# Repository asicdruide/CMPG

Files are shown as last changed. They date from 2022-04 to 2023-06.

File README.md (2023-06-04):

# CMPG
Plate Generator for CindyMill

CNC mills are cool machines. CindyMill is one of those.
see also:
* http://cindymill.xyz/ 
* https://github.com/culturalheritagedigital/Cindymill

This repository provides a set of python scripts to draw the needed parts as dxf.
Advantage is that you can easily do adaptions even if you have no access to a full blown CAD system.

It's based on python and the ezdxf module (btw great stuff).

This is work-in-progress, if you use it, you do it on your own risk.

Planned improvements:
 * ~~central setup file for all parameters~~ (done)
 * more dependencies calculated (lesser magic numbers)
 * ~~output for non-plate values like extrusion length~~ (done)
 * ~~parts library for common parts~~ (done)

### How to run

python cmpg.py 

will re-generate everything under sub-folder 'generated'.

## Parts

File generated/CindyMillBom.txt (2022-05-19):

DIN125       M3   ......................... 54 needed....stock(    ).......to be sourced(    )
    2 (mounting Z-limit switches)
    4 (mounting XY-limit switches)
    8 (Portal-side-left to Y-MGN12H)
    8 (Portal-side-right to Y-MGN12H)
   16 (ZAxis-front to Z-MGN12H)
   16 (ZAxis-back X-MGN12H)
 
DIN125       M4   .........................  6 needed....stock(    ).......to be sourced(    )
    6 (1204 nut to nut holder)
 
DIN125       M5   .........................250 needed....stock(    ).......to be sourced(    )
   18 (1605 nut to nut holder)
   16 (brackets at inner frame corners)
    8 (Frame-front-left to Y-extrusion)
    8 (Frame-front-left to frameX-extrusion)
    8 (Y-BF12 to Frame-front-left)
    8 (Frame-front-right to Y-extrusion)
    8 (Frame-front-right to frameX-extrusion)
    8 (Y-BF12 to Frame-front-right)
    8 (Frame-back-left to Y-extrusion)
    8 (Frame-back-left to frameX-extrusion)
    8 (Y-NEMA23 to Frame-back-left)
    8 (Frame-back-right to Y-extrusion)
    8 (Frame-back-right to frameX-extrusion)
    8 (Y-NEMA23 to Frame-back-right)
    8 (Y-BK12 to Frame-block-left)
    8 (Y-BK12 to Frame-block-right)
    4 (Portal-side-left to Y-1605 nut holder)
   12 (Portal-side-left to portalX-extrusion)
    8 (X-BF12 to Portal-side-left)
    4 (Portal-side-right to Y-1605 nut holder)
   12 (Portal-side-right to portalX-extrusion)
    8 (X-NEMA23 to Portal-side-right)
   20 (Portal-back to portal)
    8 (X-BK12 to Portal-block)
    4 (ZAxis-front to Z-1204 nutholder)
    2 (ZAxis-bottom to Z-extrusion)
    8 (Z-NEMA23 to ZAxis-top)
    2 (ZAxis-top to Z-extrusion)
    4 (ZAxis-back to X-1605 nutholder)
    8 (Z-extrusion to ZAxis-back)
 
DIN125       M6   ......................... 36 needed....stock(    ).......to be sourced(    )
    4 (block to Frame-back-left)
    4 (block to Frame-back-right)
    4 (Frame-block-left to Frame-back)
    4 (Frame-block-right to Frame-back)
    4 (steel socket to Portal-side-right)
    4 (Portal-block to steel socket)
    6 (spindle_adapter to ZAxis-front)
    2 (Z-BF10 to ZAxis-back)
    4 (Z-BK10 to ZAxis-back)
 
DIN912       M3x10......................... 20 needed....stock(    ).......to be sourced(    )
    4 (mounting XY-limit switches)
   16 (ZAxis-front to Z-MGN12H)
 
DIN912       M3x16......................... 34 needed....stock(    ).......to be sourced(    )
    2 (mounting Z-limit switches)
    8 (Portal-side-left to Y-MGN12H (exact:15))
    8 (Portal-side-right to Y-MGN12H (exact:15))
   16 (ZAxis-back X-MGN12H (exact:15))
 
DIN912       M3x8 .........................144 needed....stock(    ).......to be sourced(    )
   58 (Xrails to extrusion)
   64 (Yrails to extrusion)
   22 (Zrails to extrusion)
 
DIN912       M4x18.........................  6 needed....stock(    ).......to be sourced(    )
    6 (1204 nut to nut holder (exact:17))
 
DIN912       M5x14.........................  4 needed....stock(    ).......to be sourced(    )
    4 (ZAxis-front to Z-1204 nutholder (exact:13))
 
DIN912       M5x16......................... 52 needed....stock(    ).......to be sourced(    )
    8 (Frame-front-left to frameX-extrusion)
    8 (Frame-front-right to frameX-extrusion)
    8 (Frame-back-left to frameX-extrusion)
    8 (Frame-back-right to frameX-extrusion)
   20 (Portal-back to portal)
 
DIN912       M5x20......................... 18 needed....stock(    ).......to be sourced(    )
   18 (1605 nut to nut holder)
 
DIN912       M5x22.........................  8 needed....stock(    ).......to be sourced(    )
    8 (Z-extrusion to ZAxis-back (exact:23))
 
DIN912       M5x25......................... 70 needed....stock(    ).......to be sourced(    )
    8 (Frame-front-left to Y-extrusion)
    8 (Frame-front-right to Y-extrusion)
    8 (Frame-back-left to Y-extrusion)
    4 (Y-NEMA23 to Frame-back-left (exact:26))
    8 (Frame-back-right to Y-extrusion)
    4 (Y-NEMA23 to Frame-back-right (exact:26))
   12 (Portal-side-left to portalX-extrusion)
   12 (Portal-side-right to portalX-extrusion)
    2 (ZAxis-bottom to Z-extrusion)
    4 (ZAxis-back to X-1605 nutholder)
 
DIN912       M5x30.........................  6 needed....stock(    ).......to be sourced(    )
    4 (Z-NEMA23 to ZAxis-top (exact:31))
    2 (ZAxis-top to Z-extrusion)
 
DIN912       M5x35.........................  4 needed....stock(    ).......to be sourced(    )
    4 (X-NEMA23 to Portal-side-right (exact:36))
 
DIN912       M5x40......................... 12 needed....stock(    ).......to be sourced(    )
    4 (Y-BF12 to Frame-front-left)
    4 (Y-BF12 to Frame-front-right)
    4 (X-BF12 to Portal-side-left)
 
DIN912       M5x45......................... 12 needed....stock(    ).......to be sourced(    )
    4 (Y-BK12 to Frame-block-left)
    4 (Y-BK12 to Frame-block-right)
    4 (X-BK12 to Portal-block)
 
DIN912       M5x8 ......................... 16 needed....stock(    ).......to be sourced(    )
   16 (brackets at inner frame corners)
 
DIN912       M6x20......................... 14 needed....stock(    ).......to be sourced(    )
    4 (steel socket to Portal-side-right (exact:19))
    4 (Portal-block to steel socket)
    6 (spindle_adapter to ZAxis-front)
 
DIN912       M6x25......................... 16 needed....stock(    ).......to be sourced(    )
    4 (block to Frame-back-left)
    4 (block to Frame-back-right)
    4 (Frame-block-left to Frame-back)
    4 (Frame-block-right to Frame-back)
 
DIN912       M6x40.........................  6 needed....stock(    ).......to be sourced(    )
    2 (Z-BF10 to ZAxis-back)
    4 (Z-BK10 to ZAxis-back)
 
DIN985       M5   ......................... 40 needed....stock(    ).......to be sourced(    )
    4 (Y-BF12 to Frame-front-left)
    4 (Y-BF12 to Frame-front-right)
    4 (Y-NEMA23 to Frame-back-left)
    4 (Y-NEMA23 to Frame-back-right)
    4 (Y-BK12 to Frame-block-left)
    4 (Y-BK12 to Frame-block-right)
    4 (X-BF12 to Portal-side-left)
    4 (X-NEMA23 to Portal-side-right)
    4 (X-BK12 to Portal-block)
    4 (Z-NEMA23 to ZAxis-top)
 
ISO7380      M5x20.........................  8 needed....stock(    ).......to be sourced(    )
    4 (Portal-side-left to Y-1605 nut holder)
    4 (Portal-side-right to Y-1605 nut holder)
 
SlidingNut   M3   .........................150 needed....stock(    ).......to be sourced(    )
    2 (mounting Z-limit switches)
    4 (mounting XY-limit switches)
   58 (Xrails to extrusion)
   64 (Yrails to extrusion)
   22 (Zrails to extrusion)
 
SlidingNut   M5   ......................... 56 needed....stock(    ).......to be sourced(    )
   16 (brackets at inner frame corners)
    8 (Frame-front-left to frameX-extrusion)
    8 (Frame-front-right to frameX-extrusion)
    8 (Frame-back-left to frameX-extrusion)
    8 (Frame-back-right to frameX-extrusion)
    8 (Z-extrusion to ZAxis-back)
 
SteelSocket  M6x30.........................  4 needed....stock(    ).......to be sourced(    )
    4 (steel socket to Portal-side-right)
 
SteelSocket  M6x40.........................  8 needed....stock(    ).......to be sourced(    )
    4 (block to Frame-back-left)
    4 (block to Frame-back-right)
 
brackets     M5   .........................  8 needed....stock(    ).......to be sourced(    )
    8 (brackets at inner frame corners)
 
dowel pin    3x10 .........................  1 needed....stock(    ).......to be sourced(    )
    1 (dowel pin)
 
generated on Tue 2022-May-17 18:49:17

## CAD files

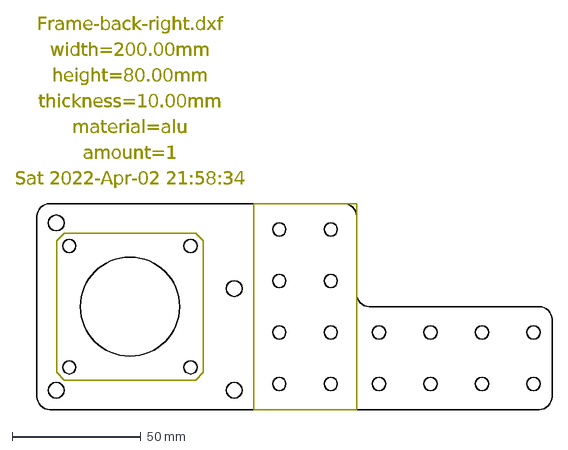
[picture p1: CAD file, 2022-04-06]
Frame/1x_10mm_Frame-back-right.dxf
Frame-back-right.dxf
width=200.00mm
height=80.00mm
thickness=10.00mm
material=alu
amount=1
Sat 2022-Apr-02 21:58:34

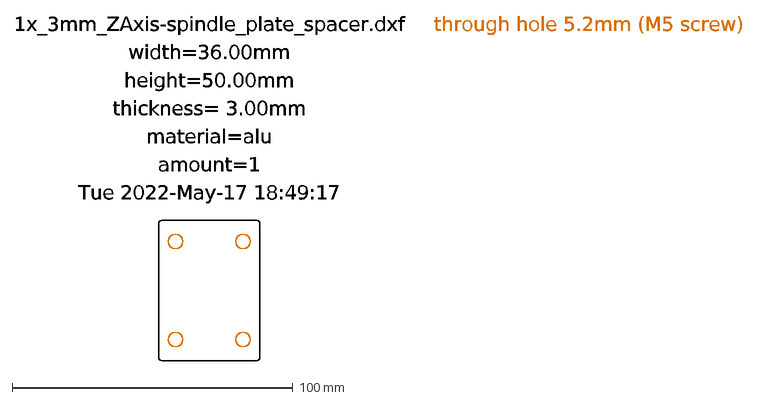
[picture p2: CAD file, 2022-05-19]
generated/1x_3mm_ZAxis-spindle_plate_spacer.dxf
1x_3mm_ZAxis-spindle_plate_spacer.dxf
width=36.00mm
height=50.00mm
thickness= 3.00mm
material=alu
amount=1
Tue 2022-May-17 18:49:17
through hole 5.2mm (M5 screw)

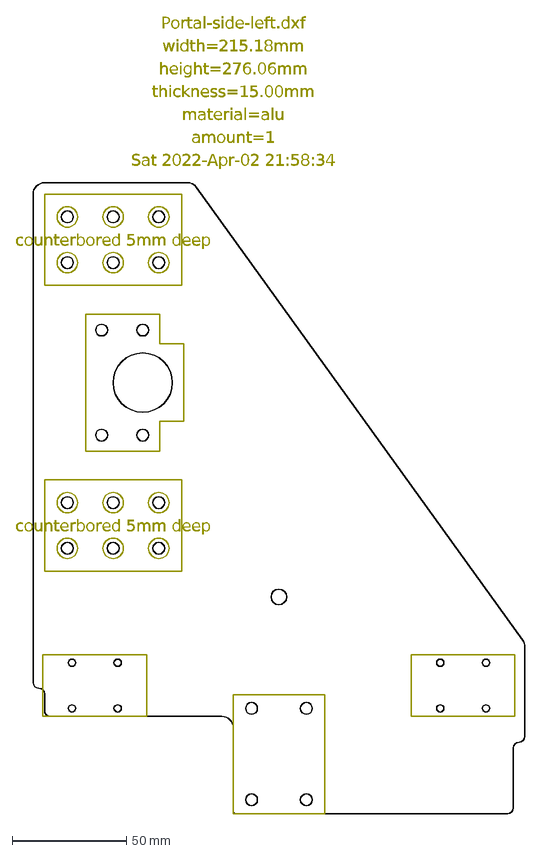
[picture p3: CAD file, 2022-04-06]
Portal/1x_15mm_Portal-side-left.dxf
counterbored 5mm deep
Portal-side-left.dxf
width=215.18mm
height=276.06mm
thickness=15.00mm
material=alu
amount=1
Sat 2022-Apr-02 21:58:34

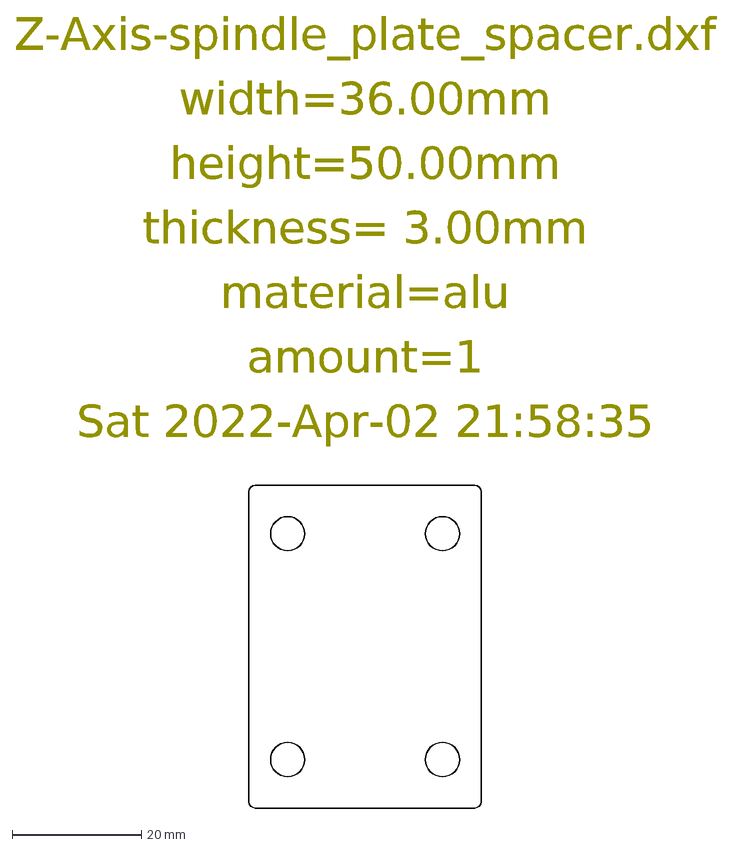
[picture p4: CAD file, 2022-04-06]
Z-Axis/1x_3mm_Z-Axis-spindle_plate_spacer.dxf
Z-Axis-spindle_plate_spacer.dxf
width=36.00mm
height=50.00mm
thickness= 3.00mm
material=alu
amount=1
Sat 2022-Apr-02 21:58:35

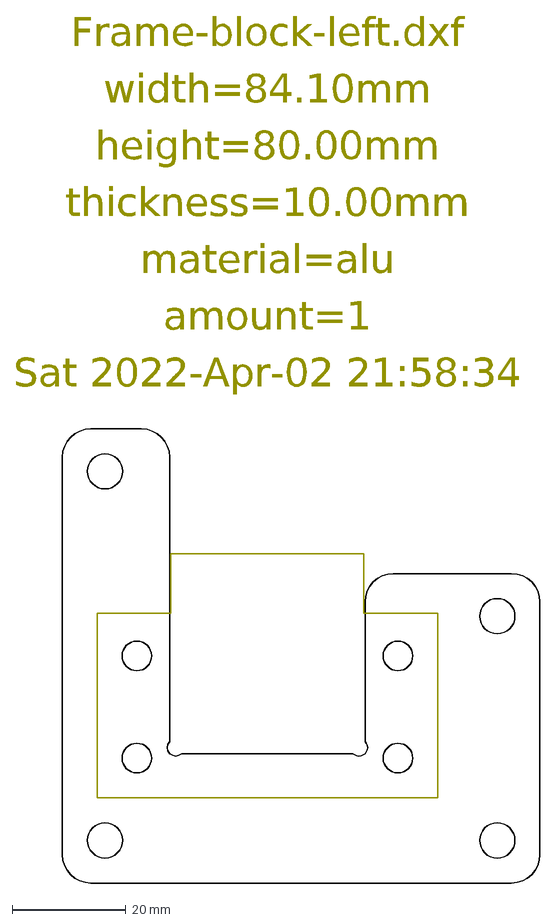
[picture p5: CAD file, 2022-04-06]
Frame/1x_10mm_Frame-block-left.dxf
Frame-block-left.dxf
width=84.10mm
height=80.00mm
thickness=10.00mm
material=alu
amount=1
Sat 2022-Apr-02 21:58:34

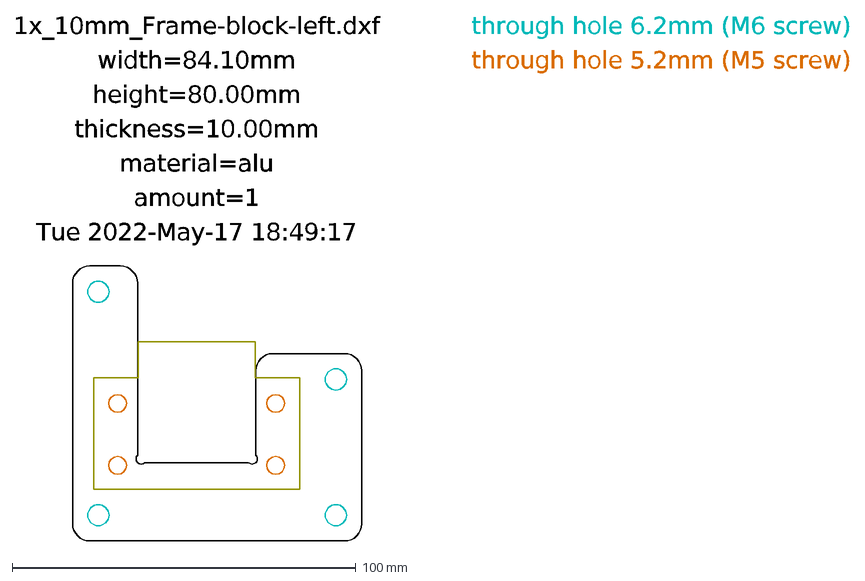
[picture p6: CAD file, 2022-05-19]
generated/1x_10mm_Frame-block-left.dxf
1x_10mm_Frame-block-left.dxf
width=84.10mm
height=80.00mm
thickness=10.00mm
material=alu
amount=1
Tue 2022-May-17 18:49:17
through hole 6.2mm (M6 screw)
through hole 5.2mm (M5 screw)

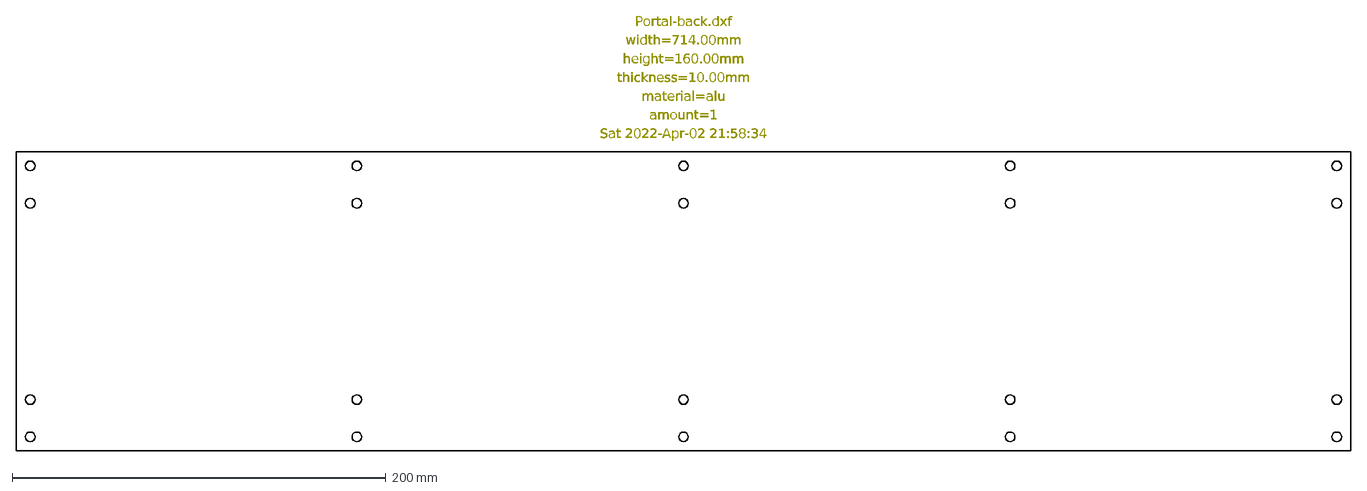
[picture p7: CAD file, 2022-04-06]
Portal/1x_10mm_Portal-back.dxf
Portal-back.dxf
width=714.00mm
height=160.00mm
thickness=10.00mm
material=alu
amount=1
Sat 2022-Apr-02 21:58:34

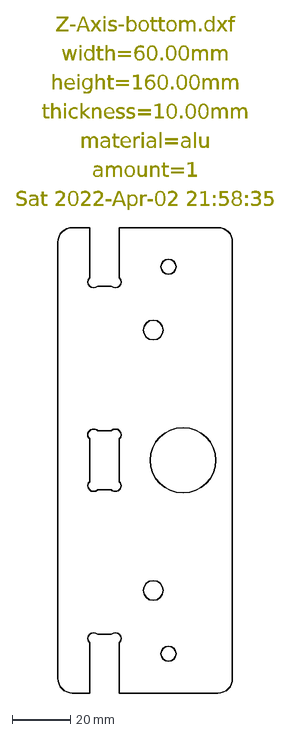
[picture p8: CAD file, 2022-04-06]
Z-Axis/1x_10mm_Z-Axis-bottom.dxf
Z-Axis-bottom.dxf
width=60.00mm
height=160.00mm
thickness=10.00mm
material=alu
amount=1
Sat 2022-Apr-02 21:58:35

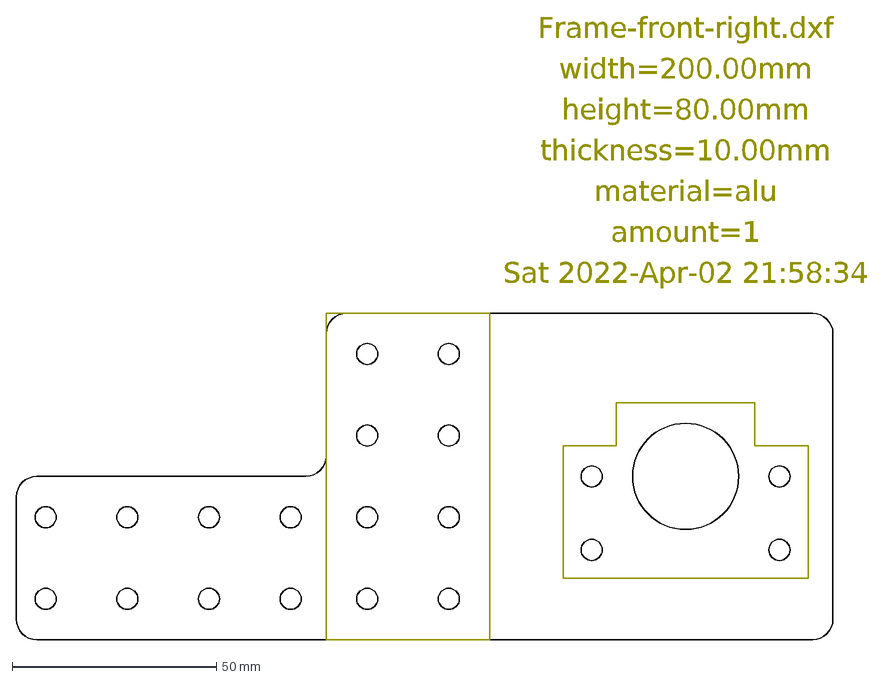
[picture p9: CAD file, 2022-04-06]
Frame/1x_10mm_Frame-front-right.dxf
Frame-front-right.dxf
width=200.00mm
height=80.00mm
thickness=10.00mm
material=alu
amount=1
Sat 2022-Apr-02 21:58:34

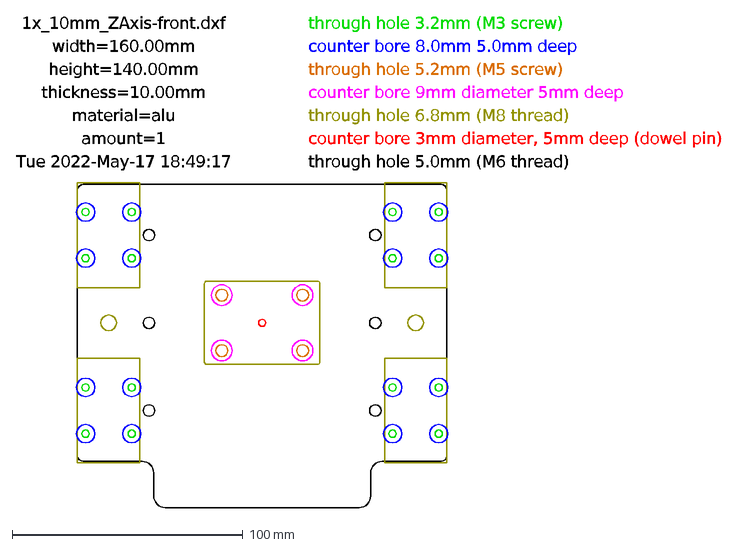
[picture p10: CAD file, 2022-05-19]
generated/1x_10mm_ZAxis-front.dxf
1x_10mm_ZAxis-front.dxf
width=160.00mm
height=140.00mm
thickness=10.00mm
material=alu
amount=1
Tue 2022-May-17 18:49:17
through hole 3.2mm (M3 screw)
counter bore 8.0mm 5.0mm deep
through hole 5.2mm (M5 screw)
counter bore 9mm diameter 5mm deep
through hole 6.8mm (M8 thread)
counter bore 3mm diameter, 5mm deep (dowel pin)
through hole 5.0mm (M6 thread)

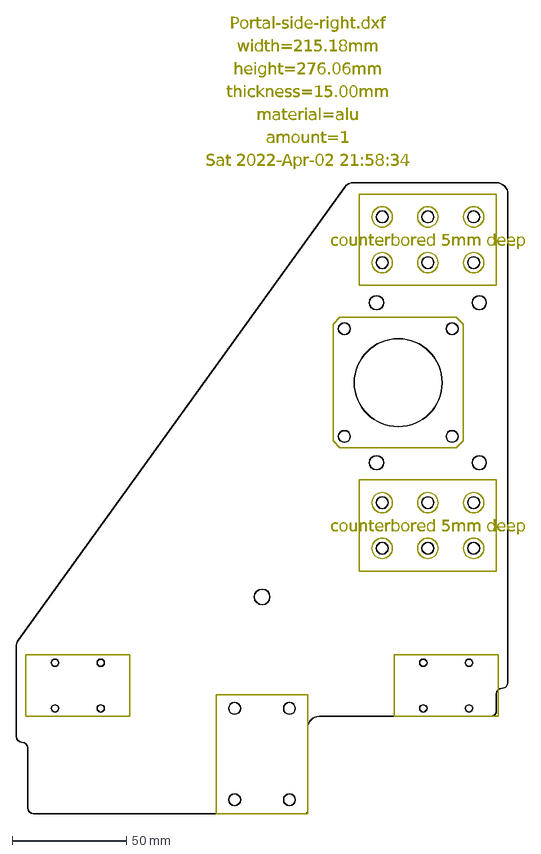
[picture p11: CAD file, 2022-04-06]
Portal/1x_15mm_Portal-side-right.dxf
counterbored 5mm deep
Portal-side-right.dxf
width=215.18mm
height=276.06mm
thickness=15.00mm
material=alu
amount=1
Sat 2022-Apr-02 21:58:34

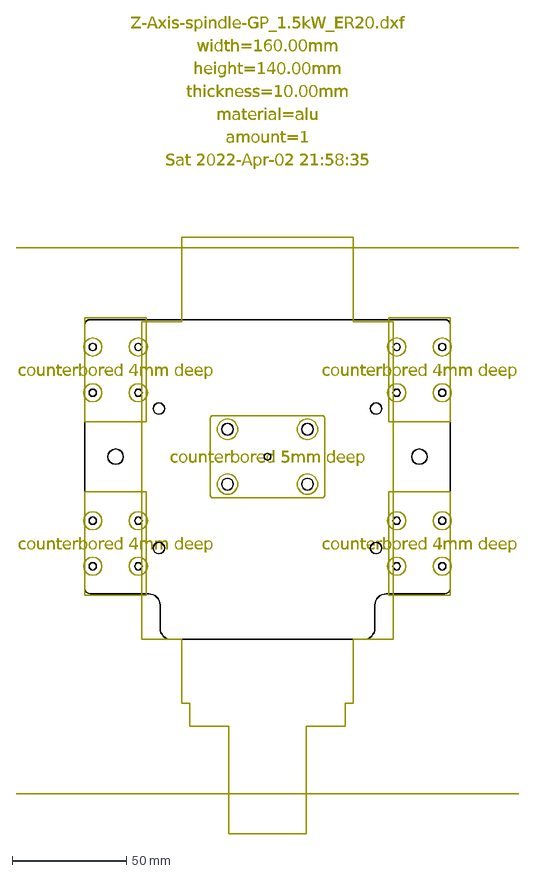
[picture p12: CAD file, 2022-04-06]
Z-Axis/1x_10mm_Z-Axis-spindle-GP_1.5kW_ER20.dxf
counterbored 4mm deep
counterbored 5mm deep
Z-Axis-spindle-GP_1.5kW_ER20.dxf
width=160.00mm
height=140.00mm
thickness=10.00mm
material=alu
amount=1
Sat 2022-Apr-02 21:58:35

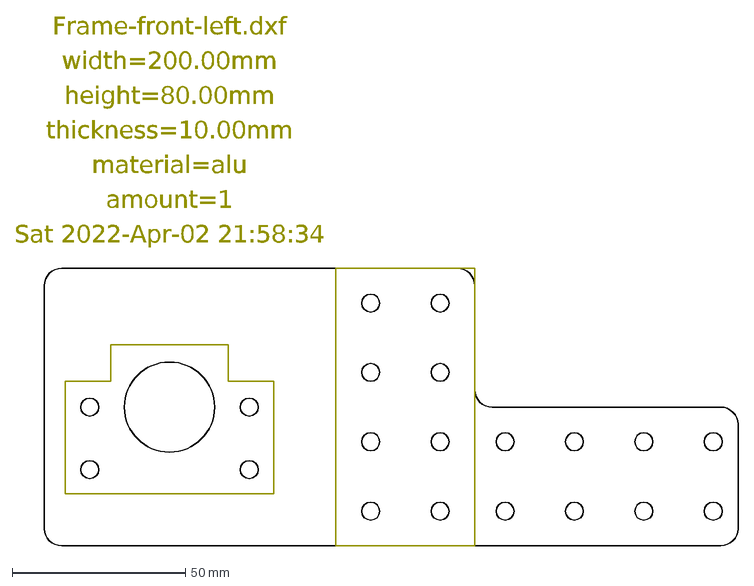
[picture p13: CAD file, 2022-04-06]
Frame/1x_10mm_Frame-front-left.dxf
Frame-front-left.dxf
width=200.00mm
height=80.00mm
thickness=10.00mm
material=alu
amount=1
Sat 2022-Apr-02 21:58:34

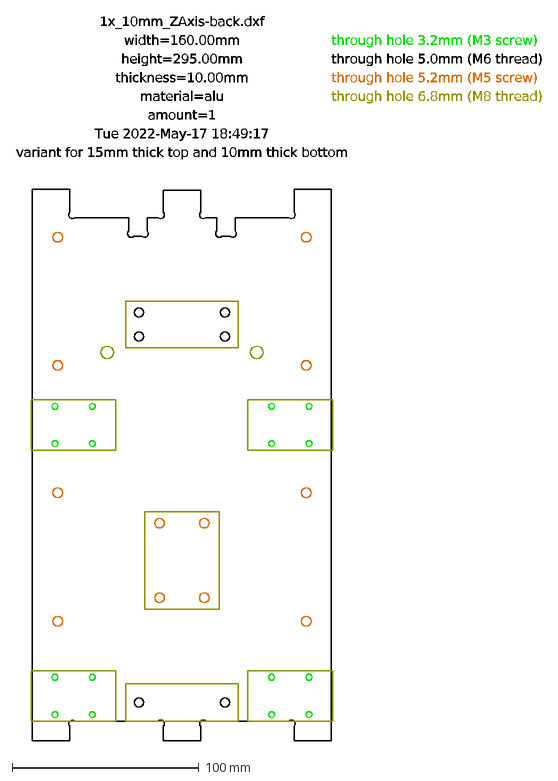
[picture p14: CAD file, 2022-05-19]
generated/1x_10mm_ZAxis-back.dxf
1x_10mm_ZAxis-back.dxf
width=160.00mm
height=295.00mm
thickness=10.00mm
material=alu
amount=1
Tue 2022-May-17 18:49:17
variant for 15mm thick top and 10mm thick bottom
through hole 3.2mm (M3 screw)
through hole 5.0mm (M6 thread)
through hole 5.2mm (M5 screw)
through hole 6.8mm (M8 thread)

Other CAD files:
XYZ-Extrusion.dxf
Portal/1x_5mm_Portal-motor_spacer.dxf
Z-Axis/1x_15mm_Z-Axis-top.dxf
Frame/1x_10mm_Frame-back-left.dxf
Frame/1x_10mm_Frame-Plate-back-left.dxf
Frame/1x_10mm_Frame-Plate-back-right.dxf
Frame/1x_10mm_Frame-Plate-block-left.dxf
Frame/1x_10mm_Frame-Plate-block-right.dxf
Frame/1x_10mm_Frame-Plate-front-left.dxf
Frame/1x_10mm_Frame-Plate-front-right.dxf
Frame/1x_10mm_Frame-block-right.dxf
Frame/Frame-Plate-back-left.dxf
Frame/Frame-Plate-back-right.dxf
Frame/Frame-Plate-block-left.dxf
Frame/Frame-Plate-block-right.dxf
Frame/Frame-Plate-front-left.dxf
Frame/Frame-Plate-front-right.dxf
Portal/1x_10mm_Portal-Plate-back.dxf
Portal/1x_10mm_Portal-Plate-block.dxf
Portal/1x_10mm_Portal-Plate-motor_spacer.dxf
Portal/1x_10mm_Portal-Plate-nut_spacer.dxf
Portal/1x_10mm_Portal-Plate-side-left.dxf
Portal/1x_10mm_Portal-Plate-side-right.dxf
Portal/1x_10mm_Portal-motor_spacer.dxf
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

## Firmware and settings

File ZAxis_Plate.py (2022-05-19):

import ezdxf
from ezdxf      import units
from datetime   import datetime
from cfg        import *
from common     import *

# - - - - - - - - - - - - - - - - - - - - - - - - - - - - - - - - - - - - - - - - - - - - - - - - - - - - - - - - -

def Spindle_adapter_connect(ctx , plate_name):
  uf = ctx['unit_factor']

  if (plate_name == 'front'):
    # on spindle plate we need an M6 threaded hole
    hole = 5.0
    EnsureLayer  (ctx , 'th50' , 'through hole 5.0mm (M6 thread)')
    layer = 'th50'
  elif (plate_name == 'spindle_adapter'):
    # on spindle adapter we need an M6 thru-hole
    hole = 6.2
    EnsureLayer  (ctx , 'th62' , 'through hole 6.2mm (M6 screw)')
    layer = 'th62'
  else:
    print("unknown context '%s' for Spindle_adapter_connect" % plate_name)
    exit(1)

  # we need holes to mount the spindle_adapter to spindle_plate
  holesY = [118
           , 80
           , 42
           ]
  for y in holesY:
    ctx['msp'].add_circle(( -49*uf , y*uf) ,   hole/2*uf, dxfattribs={'layer' : layer})
    ctx['msp'].add_circle((  49*uf , y*uf) ,   hole/2*uf, dxfattribs={'layer' : layer})

  return

# - - - - - - - - - - - - - - - - - - - - - - - - - - - - - - - - - - - - - - - - - - - - - - - - - - - - - - - - -

def SpindleAddOn(ctx , width):
  hole = 6.8
  uf = ctx['unit_factor']

  EnsureLayer  (ctx , 'th68' , 'through hole 6.8mm (M8 thread)')

  # purpose: mount dial indicator for aligning geometry
  ctx['msp'].add_circle(( (-width/2 + 13.5)*uf , 80*uf) ,   hole/2*uf, dxfattribs={'layer' : 'th68'})
  ctx['msp'].add_circle(( (+width/2 - 13.5)*uf , 80*uf) ,   hole/2*uf, dxfattribs={'layer' : 'th68'})

  return

# - - - - - - - - - - - - - - - - - - - - - - - - - - - - - - - - - - - - - - - - - - - - - - - - - - - - - - - - -

def SpindleAdapter(plate_name):
  hole = 6.8

  # on spindle plate we need holes for M6 threads (=5mm)
  # on adapter plate we need holes for M6 screws  (=6.4mm)



  return

# - - - - - - - - - - - - - - - - - - - - - - - - - - - - - - - - - - - - - - - - - - - - - - - - - - - - - - - - -

def ZAxisBackAddOn(ctx , cx , cy):
  hole = 6.8
  uf = ctx['unit_factor']

  EnsureLayer(ctx , 'th68' , 'through hole 6.8mm (M8 thread)')

  # purpose: mount for dial indicator
  ctx['msp'].add_circle(( cx*uf , cy*uf) ,   hole/2*uf , dxfattribs={'layer': 'th68'})
  ctx['msp'].add_circle((-cx*uf , cy*uf) ,   hole/2*uf , dxfattribs={'layer': 'th68'})

  return

# - - - - - - - - - - - - - - - - - - - - - - - - - - - - - - - - - - - - - - - - - - - - - - - - - - - - - - - - -

def RailMount(ctx , x , y1 , y2 , y3 , y4):
  hole = 5.2
  uf = ctx['unit_factor']

  EnsureLayer(ctx , 'th52' , 'through hole 5.2mm (M5 screw)')

  for (x,y) in [[x , y1]
               ,[x , y2]
               ,[x , y3]
               ,[x , y4]
               ]:
    ctx['msp'].add_circle(( x*uf , y*uf) , hole/2*uf , dxfattribs={'layer': 'th52'})
    ctx['msp'].add_circle((-x*uf , y*uf) , hole/2*uf , dxfattribs={'layer': 'th52'})

  return

# - - - - - - - - - - - - - - - - - - - - - - - - - - - - - - - - - - - - - - - - - - - - - - - - - - - - - - - - -

def ZAxis_Plate(ctx , plate_group , plate_name , plate_variant):
  cr    = 5                     # corner radius
  dbr   = 2.0                   # dog-bone radius => 3mm tool diameter
  cb90  = 0.4142135             # corner bulge = tan(22.5°) for 90° corners
  dbo90 = math.sqrt(2) * dbr    # dog-bone offset for 90° inner corners
  dbb   = 1                     # dogbone bulge
  uf = ctx['unit_factor']

  result = {}

  if (plate_variant==''):
    plate_id = '%s-%s'    % (plate_group,plate_name)
  else:
    plate_id = '%s-%s-%s' % (plate_group,plate_name,plate_variant)





  if (plate_name == 'bottom'):
    # x/y values under the assumption that the center of ballscrew/motor-axis is at (0,0)
    xadj = 10 - cfg['Plates'][plate_group]['back']['thickness']

    (x1,x2,x3,x4      ) = [ -43+xadj  ,  -32.15+xadj , -21.85 , 17]
    (y6,y5,y4,y3,y2,y1) = [ 80
                          , 59.85
                          , 10.15
                          ,-10.15
                          ,-59.85
                          ,-80
                          ]

    # draw outer shape...
    shape = ctx['msp'].add_lwpolyline([( (x1+cr   )*uf , (y1      )*uf , 0   ) #  1
                                      ,( (x2      )*uf , (y1      )*uf , 0   ) #  2
                                      ,( (x2      )*uf , (y2-dbo90)*uf ,-dbb ) #  3
                                      ,( (x2+dbo90)*uf , (y2      )*uf , 0   ) #  4
                                      ,( (x3-dbo90)*uf , (y2      )*uf ,-dbb ) #  5
                                      ,( (x3      )*uf , (y2-dbo90)*uf , 0   ) #  6
                                      ,( (x3      )*uf , (y1      )*uf , 0   ) #  7
                                      ,( (x4-cr   )*uf , (y1      )*uf , cb90) #  8
                                      ,( (x4      )*uf , (y1+cr   )*uf , 0   ) #  9
                                      ,( (x4      )*uf , (y6-cr   )*uf , cb90) # 10
                                      ,( (x4-cr   )*uf , (y6      )*uf , 0   ) # 11
                                      ,( (x3      )*uf , (y6      )*uf , 0   ) # 12
                                      ,( (x3      )*uf , (y5+dbo90)*uf ,-dbb ) # 13
                                      ,( (x3-dbo90)*uf , (y5      )*uf , 0   ) # 14
                                      ,( (x2+dbo90)*uf , (y5      )*uf ,-dbb ) # 15
                                      ,( (x2      )*uf , (y5+dbo90)*uf , 0   ) # 16
                                      ,( (x2      )*uf , (y6      )*uf , 0   ) # 17
                                      ,( (x1+cr   )*uf , (y6      )*uf , cb90) # 18
                                      ,( (x1      )*uf , (y6-cr   )*uf , 0   ) # 19
                                      ,( (x1      )*uf , (y1+cr   )*uf , cb90) # 20
                                      ]
                                     , format='xyb'
                                     )
    shape.close(True)

    # draw inner shape...
    shape = ctx['msp'].add_lwpolyline([( (x2+dbo90)*uf , (y3      )*uf , 0   ) #  1
                                      ,( (x3-dbo90)*uf , (y3      )*uf , dbb ) #  2
                                      ,( (x3      )*uf , (y3+dbo90)*uf , 0   ) #  3
                                      ,( (x3      )*uf , (y4-dbo90)*uf , dbb ) #  4
                                      ,( (x3-dbo90)*uf , (y4      )*uf , 0   ) #  5
                                      ,( (x2+dbo90)*uf , (y4      )*uf , dbb ) #  6
                                      ,( (x2      )*uf , (y4-dbo90)*uf , 0   ) #  7
                                      ,( (x2      )*uf , (y3+dbo90)*uf , dbb ) #  8
                                      ]
                                     , format='xyb'
                                     )
    shape.close(True)







    # add other elements...
    EnsureLayer(ctx , 'thx' , 'through hole 22.5mm')
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

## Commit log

2022-03-14 added current output files and updated README
    [#Portal-Plate-side-right.dxf, Frame-Plate-back-left.dxf, Frame-Plate-back-right.dxf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]
2022-03-15 pulled out cfg-keys
    [#Portal-Plate-side-right.dxf, Frame-Plate-back-left.dxf, Frame-Plate-back-right.dxf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]
2022-03-15 added X-frame-extrusion
    [XY-Extrusion.dxf]
2022-03-16 pulled out common parts
    [Frame-Plate-back-left.dxf, Frame-Plate-back-right.dxf, Frame-Plate-block-left.dxf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]
2022-03-17 added missing portal spacer added Z-Axis top and bottom plate
    [Portal-Plate-back.dxf, Portal-Plate-block.dxf, Portal-Plate-motor_spacer.dxf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]
2022-03-18 extended cfg structure added amount and thickness to filename
    [1x_10mm_Frame-Plate-back-left.dxf, 1x_10mm_Frame-Plate-back-right.dxf, 1x_10mm_Frame-Plate-block-left.dxf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]
2022-03-19 * added last missing plates * added timecode to annotation * mirrored some plates to get facets to preferred side
    [1x_10mm_Frame-back-left.dxf, 1x_10mm_Frame-back-right.dxf, 1x_10mm_Frame-block-left.dxf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]
2022-03-19 added output for extrusions
    [1x_10mm_Frame-back-left.dxf, 1x_10mm_Frame-back-right.dxf, 1x_10mm_Frame-block-left.dxf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]
2022-03-21 * added mm-unit to dxf * create also plain dxf (no outline or annotation) * calculate more dependencies
    [1x_10mm_Frame-back-left.dxf, 1x_10mm_Frame-back-right.dxf, 1x_10mm_Frame-block-left.dxf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]
2022-03-21 added plain dxf also for frame and portal
    [1x_10mm_Frame-back-left.dxf, 1x_10mm_Frame-back-left_plain.dxf, 1x_10mm_Frame-back-right.dxf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]
2022-03-27 * adaped some corner radices to exactly match baseline design * fixed yadj for Z-Axis-back for thicker Z-Axis-top * skipped generation of plain.dxf because other tools didn't liked disabled layers
    [1x_10mm_Frame-back-left.dxf, 1x_10mm_Frame-back-left_plain.dxf, 1x_10mm_Frame-back-right.dxf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]
2022-04-06 some minor fixes with corner radius,...
    [1x_10mm_Frame-back-left.dxf, 1x_10mm_Frame-back-right.dxf, 1x_10mm_Frame-block-left.dxf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]
2022-04-13 * major rework (all from one script) * many small issues, e.g. corner radius, fixed * added bom generation
    [1x_10mm_Frame-back-left.dxf, 1x_10mm_Frame-back-right.dxf, 1x_10mm_Frame-block-left.dxf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]
2022-04-16 * minor fix for counter bores of portal-side-left * extended bom with frame-brackets and inductive sensors
    [1x_10mm_Frame-back-left.dxf, 1x_10mm_Frame-back-right.dxf, 1x_10mm_Frame-block-left.dxf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]
2022-05-11 minor changes
    [XYZ-Extrusion.dxf]
2022-05-19 added support for other doc units than mm Internally everything is done in mm but when ezdxf gets coordinates they're scaled.
    [1x_10mm_Frame-back-left.dxf, 1x_10mm_Frame-back-right.dxf, 1x_10mm_Frame-block-left.dxf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]
